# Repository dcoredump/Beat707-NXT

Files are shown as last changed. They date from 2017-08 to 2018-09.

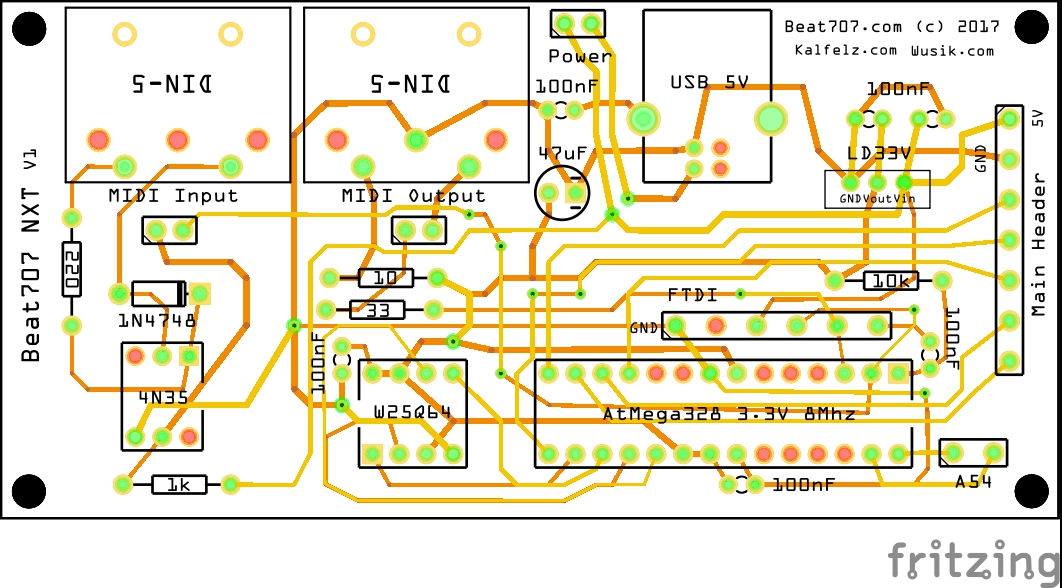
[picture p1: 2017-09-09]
Schematics/Fritzing/Beat707 NXT V1_pcb.jpg

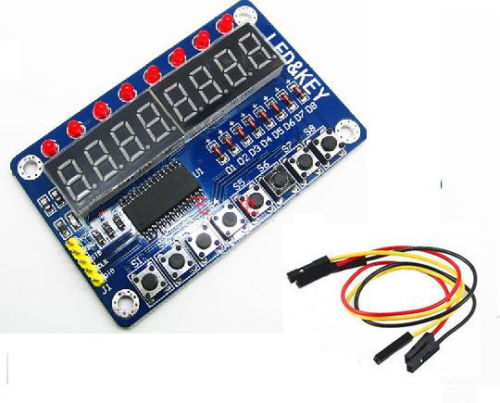
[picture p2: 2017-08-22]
Hardware/TM1638.jpg

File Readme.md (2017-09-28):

# Beat707 NXT
### Open Source Arduino Compatible MIDI Sequencer

created by William (Guilherme) Kalfelz (c) 2017

www.Beat707.com - www.Wusik.com - www.Kalfelz.com

Support us on Patreon: https://patreon.com/williamk

--------------------------------------------------------------------------------

MIDI Groove Sequencer
---------------------

- 15 Drum Tracks (note on/off, 3 velocity values).
- 1 Accent Track. But each step can be set: Accent Track, Min or Max.
- 8 Note Tracks (note number, 3 velocity values). Steps have the option of Slide, Double and Note Off.
- 28 Songs.
- 64 Patterns per Song.
- 16 Steps on screen, plus ABCD variations for a total of 64 steps.
- Double Steps (in between steps option when editing the steps). Steps are 1/16 and Double-Steps are 1/32.
- MIDI Processor Per Track. EG: Fade In, Fade Out, Fade InOut, Fade OutInt, Random Velocity and more.
- Song Mode with 64 positions. Each with Pattern Number and Options: ABCD var and repeat 0 to 15 (4 bits each).
- Echo option with the following options: track selector, number of 96 PPQ ticks, space in 96 PPQ ticks, Attach or Decay Velocity and the option to select when the echo happens: on all notes, max or lower forced velocity notes.
- Mute and Solo mode for live performance with pattern selection (settings are saved per song, not pattern).
- Simple Hardware design, based on the easy to find TM1638 IC based boards. Just search on eBay and you should be able to find several options. We used 3 boards that has 8 x buttons, 8 x LEDs and 8 x LED_Segments. The board uses a single ATmega328 running at 3.3V, one FLASH chip for storage and connections for the TM1638 boards.
- MIDI Input and Output, with Clock Send and Receive (Slave mode too).

--------------------------------------------------------------------------------

How The Software Works
----------------------

- The first TM1638 board is the main interface. Where it shows the Tempo in BPM and the current Pattern. The top leds, first 4 leds show the beat position and the last 4 leds shows the ABCD pattern variation. Also, beats will blink to bottom dot of the 4th digit from left to right.
- Still in the first board, the first button is Play, second button is Stop. 3rd is - and 4th is +. 5th, when hold, let you force a step to Max, Min or Accent. 6th button, if you press and release, will alternate mirror mode, where all ABCD variations will be edited at once, or not, when disabled. You can also hold it and select the first 4 buttons on the second board to select ABCD variations directly. The 7th button, if you press and release, will go to the next pattern. If you hold, it will show the current selected pattern on the two other boards LEDs. The final button, the 8th one, is for selecting the track been edited. If you select a track twice, it will go to the Note Track, instead of Drum Track.
- Holding button #5 from the first board and selecting the button #7, will open the pattern menu: copy, paste, init. Or selecting button #8 will open the global settings menu.
- Adding steps is easy, just click to turn On or Off. By default when you turn a step On it will use the Accent track (last track). Or you can hold button #5 from the left board and turn a step On: Max, Min and Accent. Holding a step will turn the Double-Step On/Off. The Double-Step uses the same velocity as the regular step it is on. Double-Steps are 1/32 steps.
- The Slide option for the notes work like this: regular notes will turn the previous note Off before turning the new step note On. When Slide is activated for the step, the new Step note On will come Before the previous Step Note Off. So if the target MIDI device supports Glide/Slide it will do just that.

--------------------------------------------------------------------------------

Hold Button #5 and Press Button #8, from the first board on the left.

```
  1 2 3 4 5 6 7 8 
  ---------------
          +_____+
             Global Options Menu.
```

--------------------------------------------------------------------------------

Global Options Menu
-------------------
- Button #7 is Previous Item and Button #8 is Next Item. 
- Buttons #3 and #4 are the usual - and +.
- Step buttons will select which track you are editing parameters for (when applicable).
- To exit click button #5 again.

First Board (from the left).

```
  1 2 3 4 5 6 7 8 
  ---------------
      - + E   < >
          x
          i
          t
```

Options
-------

- MIDI Channel
- MIDI Note Number (for Drum Tracks)
- MIDI Accent Value 1
- MIDI Accent Value 2
- MIDI Accent Value 3
- MIDI Processor for the current track
- ECHO Processor (6 options)
- Pattern Variations: ABCD (each variation has 16 steps)
- MIDI Sync Out: On/Off
- Current Song
- Initialize: None, Current Song or ALL (WARNING!) - hit any STEP key to start
- To Song Mode - hit + or - to go

--------------------------------------------------------------------------------

Hold Button #5 and Press Button #7, from the first board on the left.

```
  1 2 3 4 5 6 7 8
  ---------------  
          +___+
            Pattern Menu: Copy, Paste and Init.
```

--------------------------------------------------------------------------------

Pattern Menu
------------
- Just click the button next to the option you want: Copy, Paste and Init. Or hit the button #5 again to exit.

--------------------------------------------------------------------------------

Hold Button #5 and Press Button #6, from the first board on the left.

```
  1 2 3 4 5 6 7 8
  ---------------  
          +_+
           Solo Mute Mode
```

--------------------------------------------------------------------------------

Solo Mute Interface Overview 
----------------------------

```
  1 2 3 4 5 6 7 8    1 2 3 4 5 6 7 8  1 2 3 4 5 6 7 8
  ---------------    ---------------  ---------------
  { Note Tracks }    {         Drum Tracks         }Play / Stop (hold for Pattern Menu)
```

- Press buttons to Mute/UnMute and Hold for Solo. The last button on the right is for Play/Stop, hold it to open up a Pattern Menu.

--------------------------------------------------------------------------------

Solo Mute Pattern Menu
----------------------

```
  1 2 3 4 5 6 7 8    1 2 3 4 5 6 7 8  1 2 3 4 5 6 7 8
  ---------------    ---------------  ---------------
  { Pattern Bank}    {Pattern Numbr}  P   N   Close P
                                      r   e         l
                                      e   x         a
                                      v   t         y/Stop
```

--------------------------------------------------------------------------------

Interface Overview (Drum Tracks - hold a step for Double-Step)
--------------------------------------------------------------

```
  1 2 3 4 5 6 7 8    1 2 3 4 5 6 7 8  1 2 3 4 5 6 7 8
  ---------------    ---------------  ---------------
  P S - + M A P T    S S S S S S S S  S S S S S S S S
  l t     e B a r    t t t t t t t t  t t t t t t t t
  a o     n C t a    e e e e e e e e  e e e e e e e e
  y p     u D t c    p p p p p p p p  p p p p p p p p
              e k  
          A V r      0 0 0 0 0 0 0 0  0 1 1 1 1 1 1 1
          c a n      1 2 3 4 5 6 7 8  9 0 1 2 3 4 5 6
          c r
          e i
          n a
          t t
            i
            o
            n
            s
```

--------------------------------------------------------------------------------

Interface Overview (Note Tracks - to enter this mode, just hold a step)
-----------------------------------------------------------------------

```
  1 2 3 4 5 6 7 8    1 2 3 4 5 6 7 8  1 2 3 4 5 6 7 8
  ---------------    ---------------  ---------------
  P S - + M A P T    C C D D E F F G  G A A B S V O C
  l t     e B a r      #   #     #    #   #   l e c l
  a o     n C t a                             i l t o
  y p     u D t c                             d o a s
              e k                             e c v e
          A V r                                 i e
          c a n                                 t
          c r                                   y
          e i
          n a
          t t
            i
            o
            n
            s
```

--------------------------------------------------------------------------------

List of required components in order to build your unit
-------------------------------------------------------

- The Main PCB produced by us. You can order on the www.Beat707.com site.
- USB Power for the Main PCB.
- The components required by the board above. Specially the ATmega328 IC and the Flash Memory IC. The ATmega328 runs with the internal Oscillator at 8Mhz and 3.3 VCC operation. See complete list below.
- 3 x TM1638 boards such as this one: https://github.com/Beat707/Beat707-NXT/blob/master/Hardware/TM1638.jpg or from eBay: http://www.ebay.com/itm/400985462447
- A MIDI Cable and a MIDI compatible unit to produce some Audio. EG: a synth keyboard or a sound module. As the Beat707 NXT unit itself only produces MIDI, NOT Audio.
- To program the ATmega328 you will also need some sort of ISP programmer. Ordering an UNO based ATmega328 won't do, as it requires 5V and 16Mhz external oscillator to run. The easy way is to order an Arduino UNO and the USB Tiny ISP programmer to program the ATmega328 on the UNO, changing it to run on 3.3V and internal 8Mhz Oscillator. Read more below.
- The Flash memory is the Winbond W25Q64 BVAIG - DIP

--------------------------------------------------------------------------------

Connecting the boards
---------------------

- From the Main PCB you can see the Main Header, which starts from the top: 5V+, Ground, STB (Strobe), CLK (Clock), Data 1, data 2 and Data 3.
- Now, the first 4 pins are shared on all the 3 x TM1638 boards. While Data 1 is for the first board (on the left) DIO pin, data 2 is for the middle board DIO pin and finally Data 3 for the last (on the right) board DIO pin.
- The best thing is to remove the J1 headers from the TM1638 boards and just pass wires from behind the board.

Main Header (top to bottom)
---------------------------

- 5V+
- GND (Ground)
- STB (Strobe)
- CLK (Clock)
- Data 1 (DIO pin from the board on the left)
- Data 2 (DIO pin from the middle board)
- Data 3 (DIO pin from the board on the right)

--------------------------------------------------------------------------------

BOM (Build Of Materials) List for the Main PCB
----------------------------------------------
- 1x ATmega328P-PU DIP-28 - 8-Bit Microcontroller (using the internal 8Mhz Oscillator at 3.3V)
- 1x Socket for the ATmega328 IC. DIP-28.
- 1x W25Q64 DIP - 8Mbit Flash Memory Chip (3.3V)
- 1x 4N35 DIP - Octopler
- 1x 1k Ohm Resistor
- 1x 10k Ohm Resistor
- 1x 200 Ohm Resistor
- 1x 10 Ohm Resistor
- 1x 33 Ohm Resistor
- 1x 1N4748 Diode
- 2x Female Din-5 - MIDI Connector
- 1x 47uf Electrolitic Capacitor
- 4x 100nF Ceramic Capacitor
- 1x LD33V - 3.3V Voltage Regulator
- 1x Female USB-B Connector
- 3x Male Jumpers (for power, midi in and midi out. if you plan on leaving those always on, just short-solder the connections instead)
- 6x Male Headers for the FTDI Connection

--------------------------------------------------------------------------------

Programming the ATmega328 IC
----------------------------

- The board requires an ATmega328 IC that has been set to use its internal 8Mhz oscillator. So you can't just get one that has the UNO Bootloader. You will need to use an ISP programmer and connect to the ATmega328 IC and set the correct FUSES so it uses the internal 8Mhz Oscillator in order to run at 3.3V.
- One way to do this is to use the cheap USB Tiny ISP programmer and connect it to an Arduino Board which uses a DIP ATmega328, not the SMD ones.
- To set the right fuses, use the following command: avrdude -p ATMEGA328P -c usbtiny -U lfuse:w:0xe2:m -U hfuse:w:0xda:m -U efuse:w:0x05:m -C "Arduino IDE PATH\hardware\tools\avr\etc\avrdude.conf"
- Be sure to change "Arduino IDE PATH" to the correct location. In the command above I used the usbtiny programmer. Change the name for the one you are using. You can do a search for "avrdude" to check where it is located (install the Arduino IDE first).
- This must be done only one time. Now to upload to the board you can select "Arduino Pro or Pro Mini" and set to "ATmega328 8Mhz 3.3V" in the options. Only worry about the Bootloader if you plan to use the board FTDI connection.
- After programming the IC, just remove and place on the Beat707 NXT board.

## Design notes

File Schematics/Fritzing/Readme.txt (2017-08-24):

Please, support this project by purchasing the boards from our site: www.Beat707.com
Or you can also check our Patreon page: https://patreon.com/williamk
And finally my other pages: www.Wusik.com and www.Kalfelz.com
Thank you!

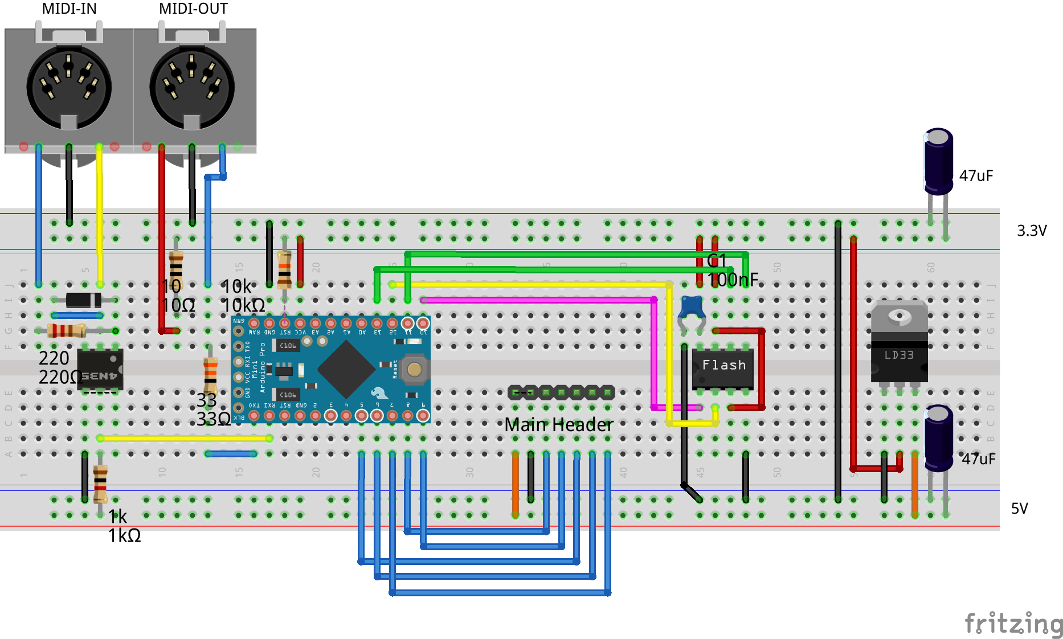
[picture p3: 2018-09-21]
Schematics/Fritzing/Beat707 NXT V1-Arduino-Mini_bb.png

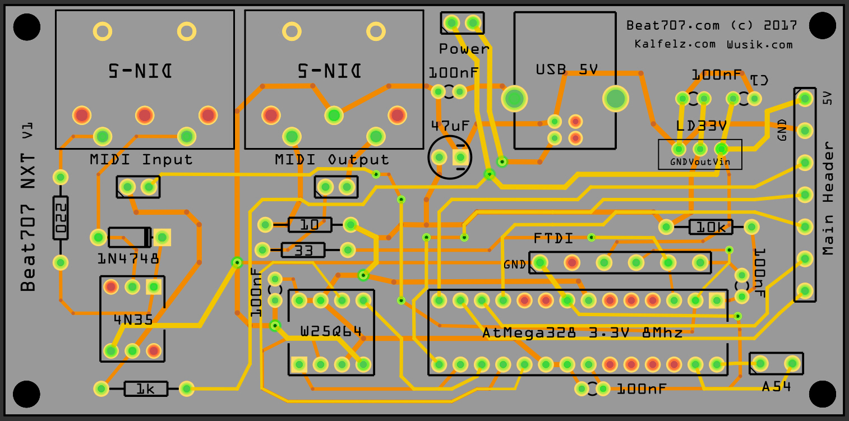
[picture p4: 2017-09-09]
Schematics/Fritzing/Beat707 NXT V1_pcb_2.jpg

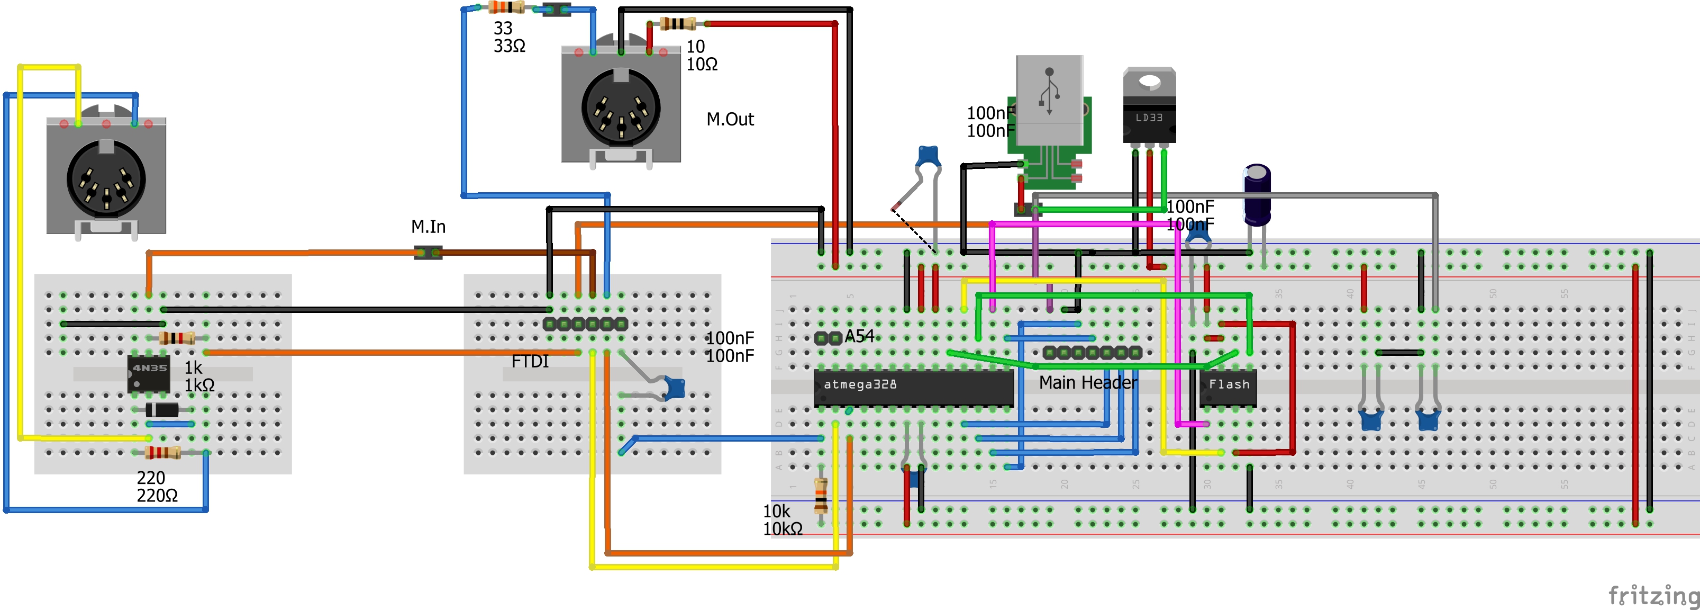
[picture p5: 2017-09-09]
Schematics/Fritzing/Beat707 NXT V1_bb.jpg

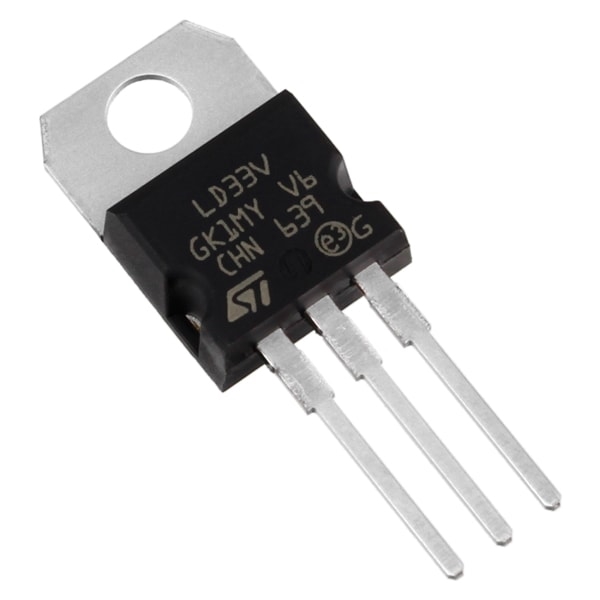
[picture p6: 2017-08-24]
Hardware/LD33V.jpg

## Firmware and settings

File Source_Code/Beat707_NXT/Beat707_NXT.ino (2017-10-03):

/*
 * 
 * Beat707 NXT - Works with 3 x TM1638 boards connected in paralel
 * Created by William Kalfelz @ Beat707 (c) 2017 - http://www.Beat707.com
 * 
 * https://github.com/Beat707/Beat707-NXT
 * 
 * Version 1.0.0 - Sep 28 2017
 * 
 */

// ------------------------------------------------------------------------------------------------------------------------------------------------------------------------------------------------------------------------------------------------
#include "X_Lib_Flash.h"

// ------------------------------------------------------------------------------------------------------------------------------------------------------------------------------------------------------------------------------------------------
#define DRUM_TRACKS 16        // This can't go above 16
#define NOTE_TRACKS 8         // This can't go above 8
#define SONG_POSITIONS 64     // Depends on RAM left, can't go above 99
#define PATTERNS 64           // This can't go above 64
#define ECHOS 6               // Depends on RAM left, usually can't go above 9
#define SONGS 30              // 30 songs should be the MAX that the Winbond chip can take
#define STEPS 16              // This can't go above 16
#define INIT_FLASH_MEMORY 0   // Warning, this will erase the entire flash contents
#define INIT_ENTIRE_FLASH 1   // When selected with the above, the entire flash chip will be erased first. This takes around 20 seconds or less to perform before we can write data to the flash chip. If this is not set, the code will erase the flash chip by sector, which takes a bit more time to perform.
#define SHOW_FREE_RAM 0       // Will show how much RAM is left on the display during initiation
#define DEBUG_SERIAL 0        // Sets the serial output to 9600 bauds and sends some debuging information out.
#define MIDI_OVER_USB 0       // When set will use 38400 bauds for the Serial interface

// ------------------------------------------------------------------------------------------------------------------------------------------------------------------------------------------------------------------------------------------------
enum
{
  fadeIn = 1, fadeOut, fadeInOut, fadeOutIn, fadeInD, fadeOutD, randomVel,
  kButtonNone = 0, kButtonClicked, kButtonHold, kButtonRelease, kButtonReleaseNothingClicked,
  kRightSteps = 0, kRightABCDVariations, kRightTrackSelection, kRightPatternSelection, kRightMenuCopyPaste, kRightMenu, kMuteSoloMenu,
  midiNoteOn = 0x90, midiNoteOff = 0x80, midiCC = 0xB0, midiChannels=16,
  patternMode = 0, songMode,
  accentTrack = (DRUM_TRACKS-1),
  echoTypeOnAllNotes = 0, echoTypeForceMaxVelocity, echoTypeForceLowVelocity,
  procFadeMin = 4, 
  menuFirst = 0, menuMidiCC = 0, menuNote, menuAccent1, menuAccent2, menuAccent3, menuProc, menuEcho, menuEchoTrack, menuEchoTicks,
  menuEchoSpace, menuEchoAttackDecay, menuEchoType, menuVariationsABCD, menuSyncOut, menuSong, menuSysex, menuInit, menuToSongMode, lastMenu = menuToSongMode, 
  kLeftMain = 0
};

// ------------------------------------------------------------------------------------------------------------------------------------------------------------------------------------------------------------------------------------------------
SPIFlash flash;
byte segments[3][8];
byte leds[3];
byte buttons[3]; // raw button values
byte buttonEvent[3][8];
byte buttonEventWasHolding[3] = {0, 0, 0};
byte buttonIsHolding[8];
byte buttonDownTime[3][8]; // time of the button press in ms
byte variation = 0; // ABCD Variations
char forceVariation = -1;
byte curTrack = 0;
bool updateScreen = true;
byte curLeftScreen = 0;
byte curRightScreen = 0;
byte currentPattern = 0;
byte nextPattern = 0;
uint16_t patternBitsSelector;
byte currentSong = 0;
bool mirror = false;
bool somethingClicked = false;
bool somethingHappened = false;
bool forceAccent = false;
bool showBPMdot = false;
byte prevVel = 1;
bool seqPlaying = false;
byte seqPosition = 0;
byte seqCounter = 0;
byte ppq24Counter = 0;
byte midiClockBeats = 0;
bool somethingChangedPattern = false; // if true saves the pattern (steps, double steps, midi processor and variations)
bool somethingChangedConfig = false; // if true saves the config data (BPM, track Note #, track MIDI CC, SeqSyncOut)
bool streamNextPattern = false;
bool loadPatternNow = false;
byte ignoreButtons = false;
byte lastVelocity = B00000011;
bool editingNote = false;
byte editStep = 0;
byte editVariation = 0;
byte prevPlayedNote[NOTE_TRACKS];
byte menuPosition = 0;
byte currentMode = patternMode;
byte songPosition = 0;
byte initMode = 0;
bool changedSong = false;
char flashHeader[8];
char songSysExDump = -2;
byte sysExDump = 0;
bool hasSoloTrack = false;
uint32_t prevMuteTrack = 0;
uint32_t prevSoloTrack = 0xFFFFFFFF;
byte totalFlashErrors = 0;
//
byte echoCounter[ECHOS][2];
byte echoVelocity[ECHOS];
byte echoTrack[ECHOS];
char echoAttackDecay[ECHOS];
byte echoSpace[ECHOS];
byte echoEdit = 0;
//
struct WECHO
{
  byte track, ticks, space, type;
  char attackDecay;
  //
  void init()
  {
    track = type = 0;
    ticks = 24;
    space = 14;
    attackDecay = 5;
  }
};
struct WSTEPS
{
  byte steps[DRUM_TRACKS]; // steps are stored as 8 bits variations in AABBCCDD format. 2 bits per step per variation. 0~3
  uint16_t stepsDouble[4]; // 16 drum tracks, 4 bits each for the ABCD variations
  byte noteSteps[NOTE_TRACKS][4];
  byte noteStepsExtras[NOTE_TRACKS][2]; // 2 bits packed as ABCD: [0] = Velocity (2 bits) ABCD, [1] = Glide/Double ABCD (2 bits)
  //
  void init()
  {
    memset(steps, 0, sizeof(steps));
    memset(stepsDouble, 0, sizeof(stepsDouble));
    memset(noteSteps, 0, sizeof(noteSteps));
    memset(noteStepsExtras, 0, sizeof(noteStepsExtras));
  }
};
struct WPATTERN // 
{
  byte totalVariations;
  byte trackProcessor[DRUM_TRACKS+NOTE_TRACKS]; 
  byte lastNote[NOTE_TRACKS];
  WECHO echoConfig[ECHOS];
  byte hasInit; // Used by the SysEx code
  //
  void init()
  {
    for (byte xe=0; xe < ECHOS; xe++) { echoConfig[xe].init(); }
    memset(trackProcessor, 0, sizeof(trackProcessor));
    memset(lastNote, 0, sizeof(lastNote));
    totalVariations = 4;
    hasInit = 0x27;
  }
};
//
struct WCONFIG
{
  byte trackNote[DRUM_TRACKS];
  byte trackMidiCH[DRUM_TRACKS+NOTE_TRACKS]; // 0~15 
  byte accentValues[3];
  byte BPM;
  boolean seqSyncOut;
  uint32_t muteTrack;
  uint32_t soloTrack;
  byte hasInit; // Used by the SysEx code
  //
  void init()
  {
    trackNote[0] = 36;
    trackNote[1] = 40;
    trackNote[2] = 42;
    trackNote[3] = 44;
    trackNote[4] = 46;
    trackNote[5] = 48;
    trackNote[6] = 49;
    trackNote[7] = 50;
    trackNote[8] = 51;
    trackNote[9] = 52;
    trackNote[10] = 53;
    trackNote[11] = 54;
    trackNote[12] = 55;
    trackNote[13] = 56;
    trackNote[14] = 57;
    trackNote[15] = 0;
    //
    memset(trackMidiCH, 9, sizeof(trackMidiCH));
    for (byte x = 0; x < 8; x++) { trackMidiCH[DRUM_TRACKS+x] = x; }
    muteTrack = soloTrack = 0;
    BPM = 120;
    hasInit = 0x27;
    seqSyncOut = false;
    accentValues[0] = 80;
    accentValues[1] = 100;
    accentValues[2] = 127;
  }
};
//
struct WSONG
{
  byte pattern[2][SONG_POSITIONS]; // Pattern Number and Options: ABCD var and repeat 0 to 15 (4 bits each)
  char loopTo;
  byte hasInit; // Used by the SysEx code
  //
  void init()
  {
    memset(pattern, 0, sizeof(pattern));
    loopTo = -1; // No Loop //
    for (byte x=0; x < SONG_POSITIONS; x++) { pattern[1][x] = 4 << 4; }
    hasInit = 0x27;
  }
};
//
WSTEPS stepsData[STEPS];
WPATTERN patternData;
WCONFIG configData;
WSONG songData;

// ------------------------------------------------------------------------------------------------------------------------------------------------------------------------------------------------------------------------------------------------
void setup() 
{
  startMIDIinterface();
  initTM1638();
  reset();
  #if SHOW_FREE_RAM
    freeMemory();
    sendScreen();
    delay(2000);
  #endif 
  flashInit(false);
  //
  startTimer();
}

// ------------------------------------------------------------------------------------------------------------------------------------------------------------------------------------------------------------------------------------------------
void reset()
{
  createFlashHeader(currentSong);
  resetSegments(0, 2);
  memset(echoSpace, 0, sizeof(echoSpace));
  memset(echoAttackDecay, 0, sizeof(echoAttackDecay));
  memset(echoTrack, 0, sizeof(echoTrack));
  memset(leds, 0, sizeof(leds));
  memset(buttons, 0, sizeof(buttons));  
  memset(buttonEvent, 0, sizeof(buttonEvent));
  memset(buttonDownTime, 0, sizeof(buttonDownTime));
  memset(prevPlayedNote, 0, sizeof(prevPlayedNote));
  memset(echoCounter, 0, sizeof(echoCounter));
  memset(echoVelocity, 0, sizeof(echoVelocity));
  configData.init();
  bitSet(patternBitsSelector,0);
  bitSet(patternBitsSelector,8);
  //
  songData.init();
  resetPattern();
}

// ------------------------------------------------------------------------------------------------------------------------------------------------------------------------------------------------------------------------------------------------
void resetPattern()
{
  for (byte x=0; x < 4; x++) 
  { 
    stepsData[0 + (x*4)].init(); 
    stepsData[1 + (x*4)].init(); 
    stepsData[2 + (x*4)].init(); 
    stepsData[3 + (x*4)].init(); 
    //
    stepsData[0 + (x*4)].steps[15] = B11111111;
    stepsData[1 + (x*4)].steps[15] = B10101010;
    stepsData[2 + (x*4)].steps[15] = B01010101;
    stepsData[3 + (x*4)].steps[15] = B10101010;
    
  }
  patternData.init();  
}

// ------------------------------------------------------------------------------------------------------------------------------------------------------------------------------------------------------------------------------------------------
void loop() 
{
  checkPatternStream();
  readButtons();
  if (currentMode == patternMode) checkInterface(); else songInterface();
  //
  if (updateScreen)
  {
    updateScreen = false;
    if (currentMode == patternMode) createScreen(); else createSongScreen();
    sendScreen();
  }
}

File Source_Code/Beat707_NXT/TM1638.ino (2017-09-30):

/*
 * 
 * Created by William Kalfelz @ Beat707 (c) 2017 - http://www.Beat707.com
 * 
 */

// ------------------------------------------------------------------------------------------------------------------------------------------------------------------------------------------------------------------------------------------------
#define STROBE 8
#define CLOCK 9
#define SETIO1 5
#define SETIO2 6
#define SETIO3 7
#define BUTTON_HOLD 200
#define BUTTON_CLICK 10

// ------------------------------------------------------------------------------------------------------------------------------------------------------------------------------------------------------------------------------------------------
void initTM1638()
{
  pinMode(STROBE, OUTPUT);
  pinMode(CLOCK, OUTPUT);
  pinMode(SETIO1, OUTPUT);
  pinMode(SETIO2, OUTPUT);
  pinMode(SETIO3, OUTPUT);
  //
  digitalWrite(STROBE, HIGH);
  digitalWrite(CLOCK, HIGH);
  digitalWrite(SETIO1, LOW);
  digitalWrite(SETIO2, LOW);
  digitalWrite(SETIO3, LOW);
  //
  sendData(0x8F); // Init
  //
  sendData(0x40); // set auto increment mode
  digitalWrite(STROBE, LOW);
  sendDataConst(0xc0, 0xc0, 0xc0); // Start Address
  digitalWrite(SETIO1, LOW);
  digitalWrite(SETIO2, LOW);
  digitalWrite(SETIO3, LOW);
  for(uint8_t i = 0; i < (16 * 8); i++)
  {
    digitalWrite(CLOCK, LOW);
    digitalWrite(CLOCK, HIGH);
  }
  digitalWrite(STROBE, HIGH);
}

// ------------------------------------------------------------------------------------------------------------------------------------------------------------------------------------------------------------------------------------------------
void sendData(byte data)
{
  digitalWrite(STROBE, LOW);
  for (byte x=0; x<8; x++)
  {
    digitalWrite(CLOCK, LOW);
    byte dataOut = bitRead(data, x);
    digitalWrite(SETIO1, dataOut);
    digitalWrite(SETIO2, dataOut);
    digitalWrite(SETIO3, dataOut);
    digitalWrite(CLOCK, HIGH);
  }
  digitalWrite(STROBE, HIGH);
}

// ------------------------------------------------------------------------------------------------------------------------------------------------------------------------------------------------------------------------------------------------
void sendDataConst(byte data1, byte data2, byte data3)
{
  for (byte x=0; x<8; x++)
  {
    digitalWrite(CLOCK, LOW);
    digitalWrite(SETIO1, bitRead(data1, x));
    digitalWrite(SETIO2, bitRead(data2, x));
    digitalWrite(SETIO3, bitRead(data3, x));
    digitalWrite(CLOCK, HIGH);
  }
}

// ------------------------------------------------------------------------------------------------------------------------------------------------------------------------------------------------------------------------------------------------
void sendScreen()
{
  sendData(0x40); // set auto increment mode
  digitalWrite(STROBE, LOW);
  sendDataConst(0xc0, 0xc0, 0xc0); // Start Address
  for (byte x=0; x<8; x++)
  {
    sendDataConst(segments[0][x], segments[1][x], segments[2][x]);
    sendDataConst(bitRead(leds[0],x), bitRead(leds[1],x), bitRead(leds[2],x));
  }
  digitalWrite(STROBE, HIGH);
}

// ------------------------------------------------------------------------------------------------------------------------------------------------------------------------------------------------------------------------------------------------
/*void sendPartialScreenSegment(byte address, byte segment)
{
  sendData(0x44);
  digitalWrite(STROBE, LOW);
  sendDataConst(0xc0 + address, 0xc0 + address, 0xc0 + address); // Start Address
  sendDataConst(segments[0][segment], segments[1][segment], segments[2][segment]);
  digitalWrite(STROBE, HIGH);
}*/

// ------------------------------------------------------------------------------------------------------------------------------------------------------------------------------------------------------------------------------------------------
void readButtons(void)
{
  digitalWrite(STROBE, LOW);
  sendDataConst(0x42, 0x42, 0x42); // Request Button States
  //
  pinMode(SETIO1, INPUT);
  pinMode(SETIO2, INPUT);
  pinMode(SETIO3, INPUT);
  //
  buttons[0] = buttons[1] = buttons[2] = 0x00;
  for (byte i = 0; i < 4; i++)
  {
    byte v[3] = { 0x00, 0x00, 0x00 };
    for (byte x=0; x<8; x++)
    {
      digitalWrite(CLOCK, LOW);
      if (digitalRead(SETIO1)) bitSet(v[0], x);
      if (digitalRead(SETIO2)) bitSet(v[1], x);
      if (digitalRead(SETIO3)) bitSet(v[2], x);
      digitalWrite(CLOCK, HIGH);
    }
    buttons[0] |= v[0] << i;
    buttons[1] |= v[1] << i;
    buttons[2] |= v[2] << i;
  }
  // 
  pinMode(SETIO1, OUTPUT);
  pinMode(SETIO2, OUTPUT);
  pinMode(SETIO3, OUTPUT);
  digitalWrite(STROBE, HIGH);
  //
  //uint32_t t = millis();
  for (byte x=0; x < 8; x++)
  {
    for (byte i = 0; i < 3; i++)
    {
      if (bitRead(buttons[i], x) && (!ignoreButtons || (i == 0 && x <= 1 && curRightScreen != kMuteSoloMenu) || (i == 2 && x == 7 && curRightScreen == kMuteSoloMenu)))
      {
        if (buttonDownTime[i][x] < BUTTON_HOLD) buttonDownTime[i][x]++;
        if ((buttonDownTime[i][x] >= BUTTON_HOLD && !bitRead(buttonEventWasHolding[i], x)) ||
            (i == 0 && curRightScreen != kMuteSoloMenu && (x >= 6 || x == 4) && buttonDownTime[i][x] > BUTTON_CLICK && !bitRead(buttonEventWasHolding[i],x)))
        {
          somethingClicked = false;
          bitSet(buttonEventWasHolding[i], x);
          if (i == 0 && curRightScreen != kMuteSoloMenu && (x == 2 || x == 3))
          {
            buttonEvent[i][x] = kButtonClicked;
            bitClear(buttonEventWasHolding[i], x);
          }
          else 
          {
            buttonEvent[i][x] = kButtonHold;
          }
          somethingHappened = true;
        }
      }
      else
      {
        if (buttonDownTime[i][x] > 0)
        {
          if ((buttonDownTime[i][x]) > BUTTON_CLICK)
          {
            if ((buttonDownTime[i][x]) >= BUTTON_HOLD || bitRead(buttonEventWasHolding[i], x))
            {
              if (somethingClicked) buttonEvent[i][x] = kButtonRelease; else buttonEvent[i][x] = kButtonReleaseNothingClicked;
              if (buttonEvent[i][x] == kButtonReleaseNothingClicked && i == 0 && x == 6 && curRightScreen != kMuteSoloMenu && buttonDownTime[i][x] >= BUTTON_HOLD) buttonEvent[i][x] = kButtonRelease;
              somethingHappened = true;
            }
            else 
            {
              if ((buttonDownTime[i][x]) < BUTTON_HOLD) 
              {
                buttonEvent[i][x] = kButtonClicked;
                somethingHappened = true;
              }
              somethingClicked = true;
            }
          }
        }
        buttonDownTime[i][x] = 0;
        bitClear(buttonEventWasHolding[i], x);
      }
    }
  }
}
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

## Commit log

2017-08-24 V1 updates
    [Beat707 NXT V1.fzz]
2017-09-24 Added ECHO
    [Beat707 NXT V1.fzz]
2017-09-27 Updated the Mute Solo Code
    Now when you mute or solo a track, it will take care of doing the
    correct note Offs for the required tracks.
    [Beat707_NXT.ino, FLASH.ino, X_Lib_Flash.h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]
2017-09-28 Mute and Solo Track updates
    Now they are saved per song, and not per pattern.
2017-09-30 SysEx Dump Prototype
2018-04-09 Converted Fritzing to Arduino-Mini-3.3V
    [Beat707 NXT V1-Arduino-Mini.fzz]
2018-04-10 Moved to only one breadboard.
    [Beat707 NXT V1-Arduino-Mini.fzz]
2018-09-21 Fixed two wrong wires. Many thanks to @wolfpaw98!
    [Beat707 NXT V1-Arduino-Mini.fzz]
